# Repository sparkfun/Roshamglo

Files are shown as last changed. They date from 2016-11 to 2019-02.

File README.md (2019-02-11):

SparkFun Roshamglo
=============================================
Giveaway rock, paper, scissors laser tag badge.
SparkFun Roshamglo (https://cdn.sparkfun.com/assets/parts/1/1/9/8/7/14107-01.jpg)

[*SparkFun Roshamglo (KIT-14130)*](https://www.sparkfun.com/products/14130)

The SparkFun Roshamglo is a badge that can be worn with a lanyard clip that has been designed to play Rock Paper Scissors. The board uses the ATtiny84, and has an IR LED and receiver to communicate between badges. To play, simply point the USB connector at your opponents controller up to 5 feet away and press the 5-way switch to the left for rock, up for paper, and right for scissors. The red/green LED will display a solid red for lose, green for win, or alternate red and green for a tie. The Roshamglo uses the [Micronucleaus](https://github.com/micronucleus/micronucleus) bootloader, which allows for USB programming from the Arduino IDE. 
 
 Repository Contents
-------------------
* **/Artwork** - Artwork for custom images (.svg)
* **/Bootloader** - Files needed to install the Micronucleaus bootloader
* **/Datasheets** - Datasheets for various components used (.pdf)
* **/Firmware** - Code used to play Rock Paper Scissors (.ino)
* **/Hardware** - All Eagle design files (.brd, .sch, .dxf, .lbr, .scr)

Documentation
--------------
* **[Hookup Guide](https://learn.sparkfun.com/tutorials/roshamglo-hookup-guide)** - Basic hookup guide.
* **[Roshamglo Project: TV-B-Gone](https://learn.sparkfun.com/tutorials/roshamglo-project-tv-b-gone)**
* **[Hack Your Roshamglo Badge](https://learn.sparkfun.com/tutorials/hack-your-roshamglo-badge)** 

License Information
-------------------
The hardware is released under [Creative Commons ShareAlike 4.0 International](https://creativecommons.org/licenses/by-sa/4.0/).
The code is beerware; if you see me (or any other SparkFun employee) at the local, and you've found our code helpful, please buy us a round!

Distributed as-is; no warranty is given.

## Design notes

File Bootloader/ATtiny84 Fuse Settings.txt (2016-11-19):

avrdude.exe -c arduino -p t84 -P <COM PORT> -b 19200 -U lfuse:w:0xe2:m -U hfuse:w:0xdd:m -U efuse:w:0xfe:m

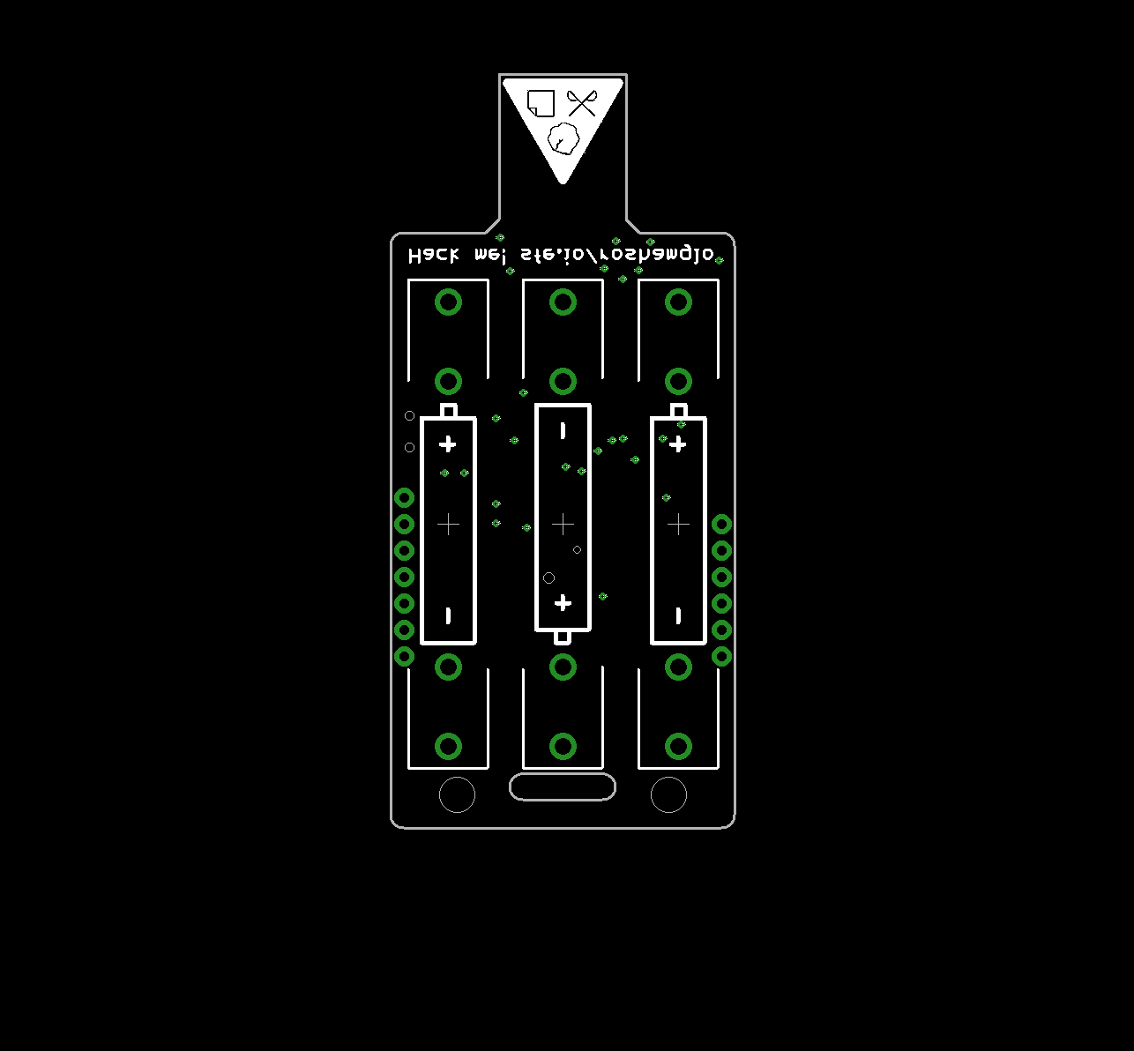
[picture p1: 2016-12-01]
Artwork/Mock-up/roshamglo_bot.png

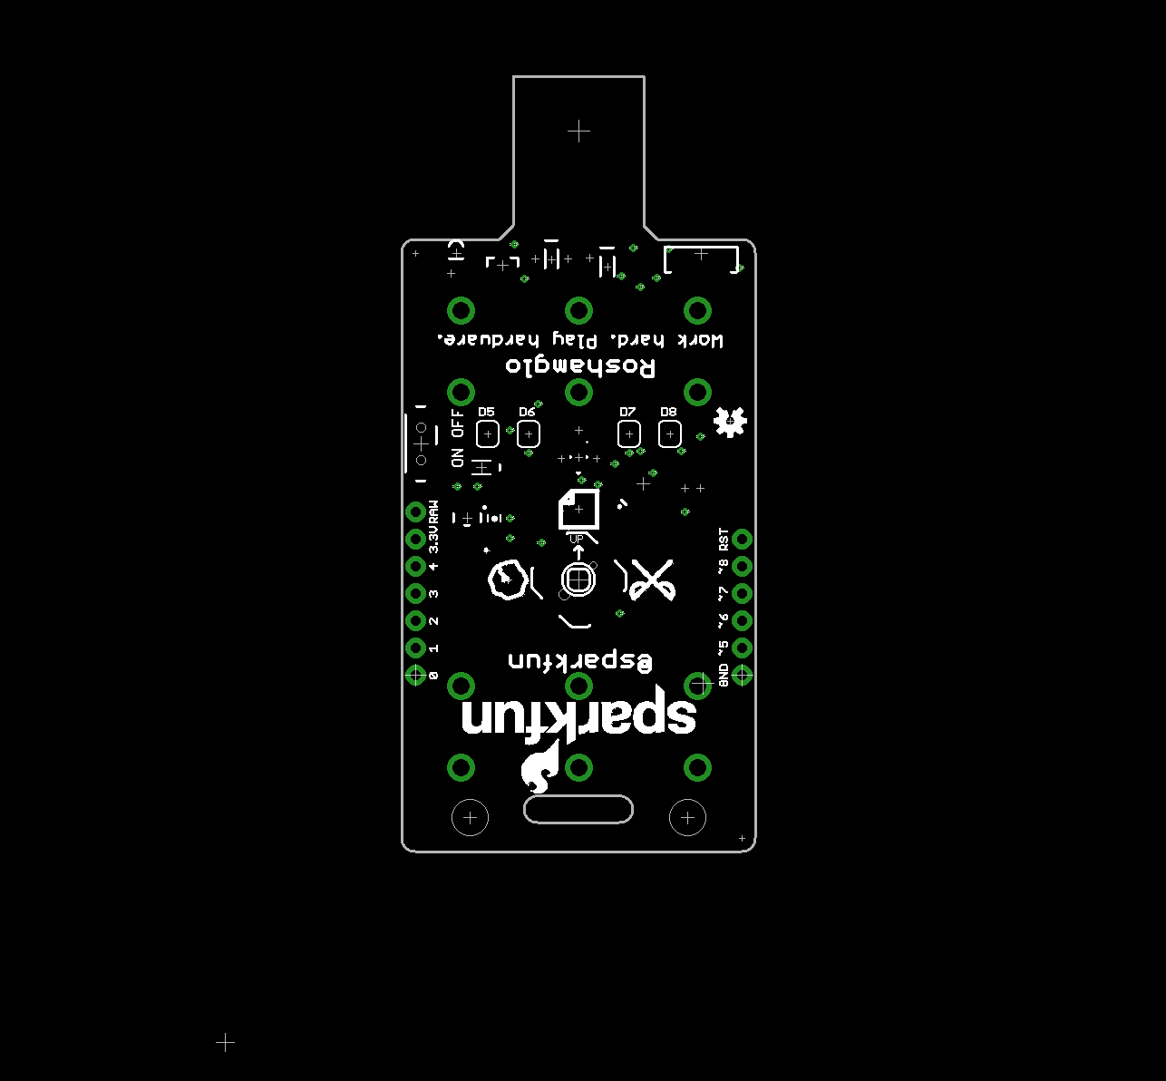
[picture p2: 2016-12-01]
Artwork/Mock-up/roshamglo_top.png

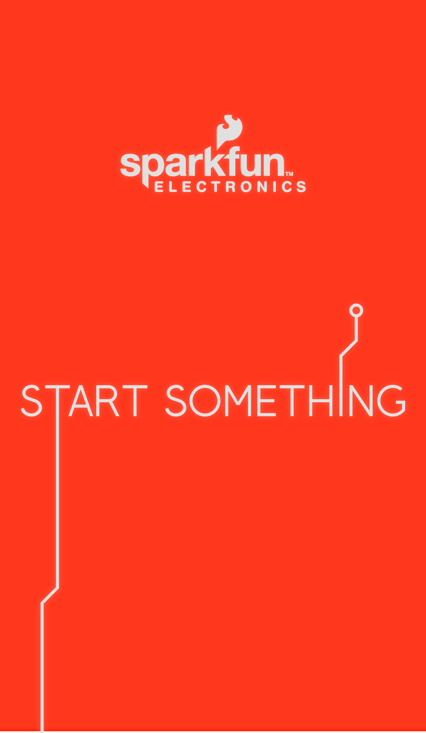
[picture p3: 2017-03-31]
Software/Scoreboard/Scoreboard/startsomething.png

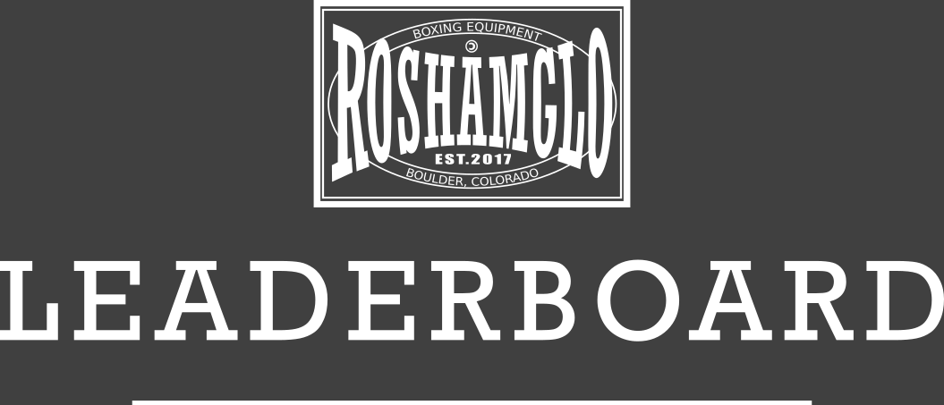
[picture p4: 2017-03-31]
Software/Scoreboard/Scoreboard/roshamglo.png

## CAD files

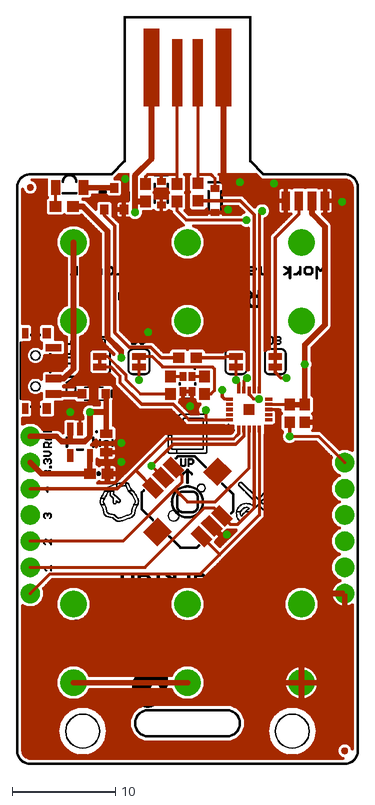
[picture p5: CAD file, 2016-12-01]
Hardware/SparkFun_Roshamglo.dxf
33.2 x 72.6

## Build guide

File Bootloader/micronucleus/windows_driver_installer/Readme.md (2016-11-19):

# Windows driver installation with Zadig #

Zadig is an automated windows driver installer for libusb devices. It will automatically create a driver signature, which prevents issues with unsigned drivers on Windows 10 and earlier. The latest version of Zadig can be found here: [http://zadig.akeo.ie/](http://zadig.akeo.ie/). For convenience, a copy is provided in this folder.

Please proceed as follows to install the Micronucleus driver:

1. Run Zadig_2.1.2.exe. The interface, as shown below, appears.
2. In the menu, go to *Device->Load Preset Device*.  Select micronucleus.cfg.
3. Click the "Install Driver" button.

The driver is now installed and Micronucleus should be ready to use. 

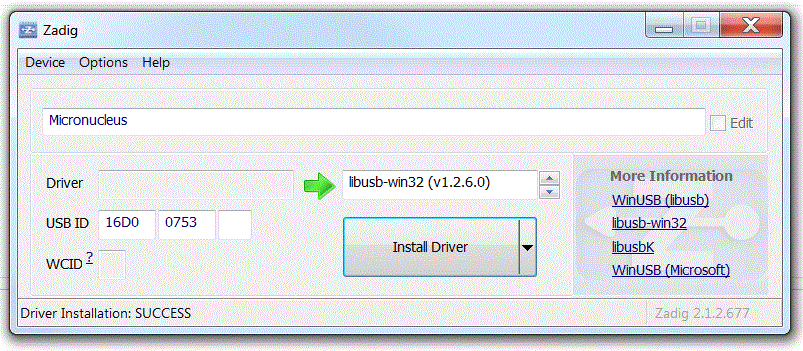
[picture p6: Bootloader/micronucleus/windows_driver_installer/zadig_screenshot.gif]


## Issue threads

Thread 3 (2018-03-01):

Scoreboard Installation Instructions

d1runberg, 2018-03-01:
It would be nice to have a README / setup instructions for the scoreboard side of things in the repo. I will see what I can do to dig in and look at it.  @NPoole do you have any thoughts / willing to do so, it would be ideal, but I know you are on other things ;)

vglisin, 2022-12-24:
Ddi you manage to connect Roshamglo and use it in Arduino IDE? The link provided from https://learn.sparkfun.com/tutorials/hack-your-roshamglo-badge:

https://raw.githubusercontent.com/sparkfun/Arduino_Boards/tiny/IDE_Board_Manager/package_sparkfun_index.json

doesn't exist... 404

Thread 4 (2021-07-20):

Arduino IDE and Roshamglo setup

vglisin, 2021-07-20:
Hello all,
I just tried to hook-up my Roshamglo (got it from friend) and followed the instructions from sparkfun but Arduino IDE definition for Roshamglo are not working. Link mentioned in text is 404:

https://raw.githubusercontent.com/sparkfun/Arduino_Boards/tiny/IDE_Board_Manager/package_sparkfun_index.json

Can you please update documents or make this link working?

Best regards,

vglisin, 2022-12-24:
Stilll doesn't work (404):

https://raw.githubusercontent.com/sparkfun/Arduino_Boards/tiny/IDE_Board_Manager/package_sparkfun_index.json

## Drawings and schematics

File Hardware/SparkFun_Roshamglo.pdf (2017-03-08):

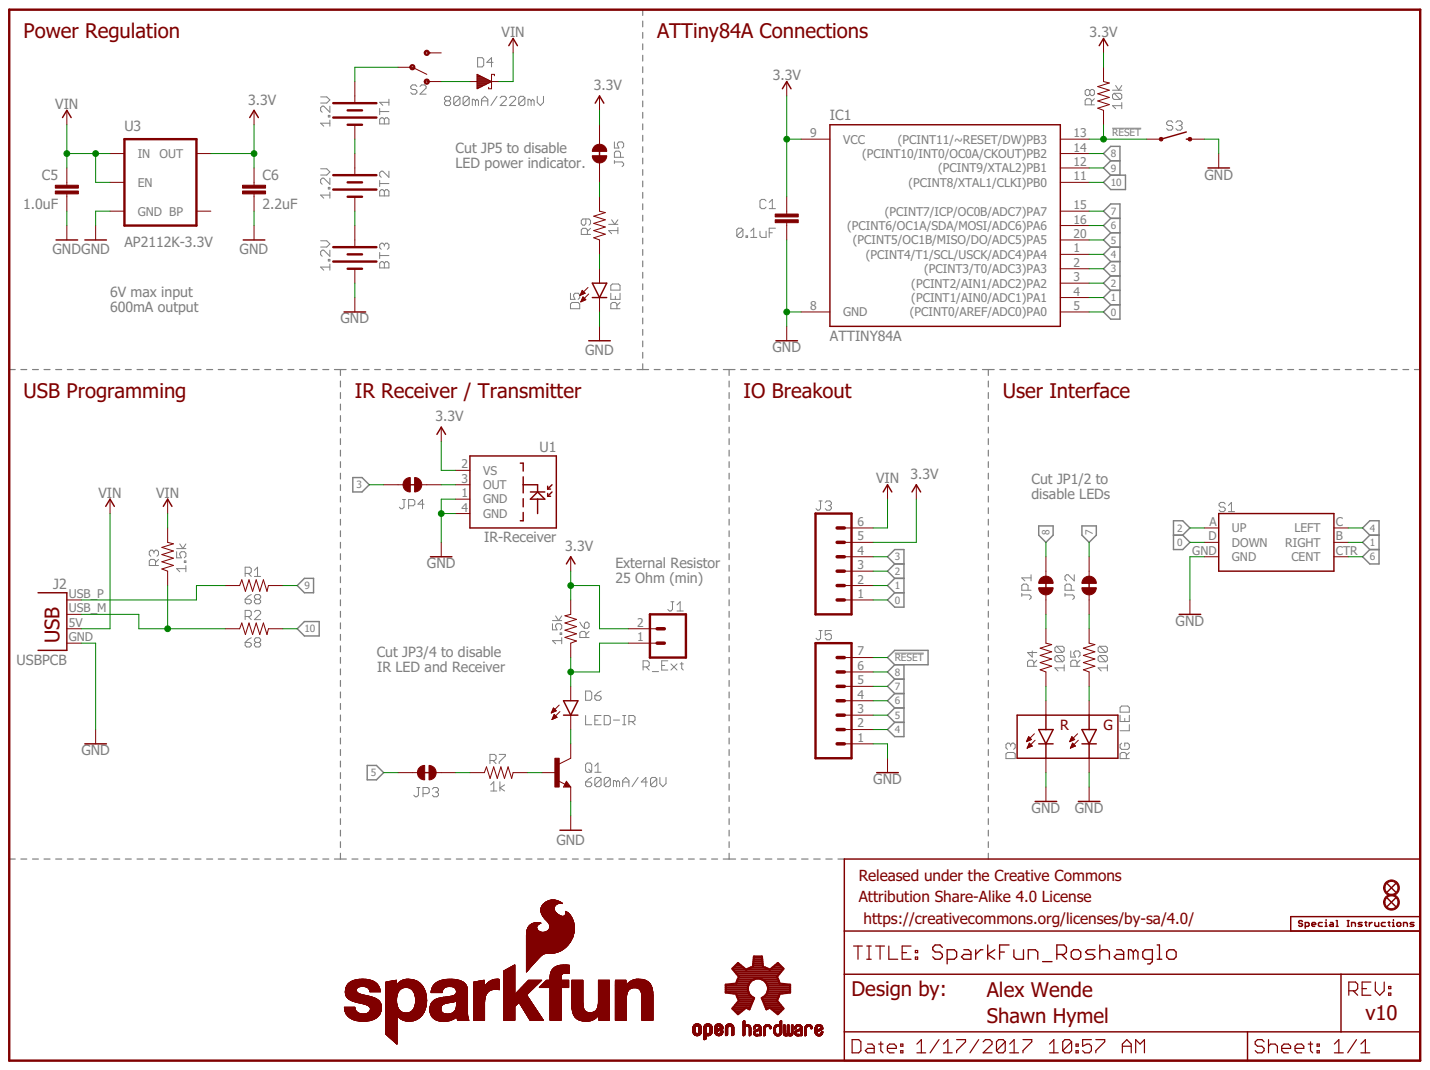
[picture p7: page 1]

Cut JP1/2 to disable LEDs

External Resistor 25 Ohm (min)

Cut JP3/4 to disable
IR LED and Receiver

Released under the Creative Commons Attribution Share-Alike 4.0 License https://creativecommons.org/licenses/by-sa/4.0/

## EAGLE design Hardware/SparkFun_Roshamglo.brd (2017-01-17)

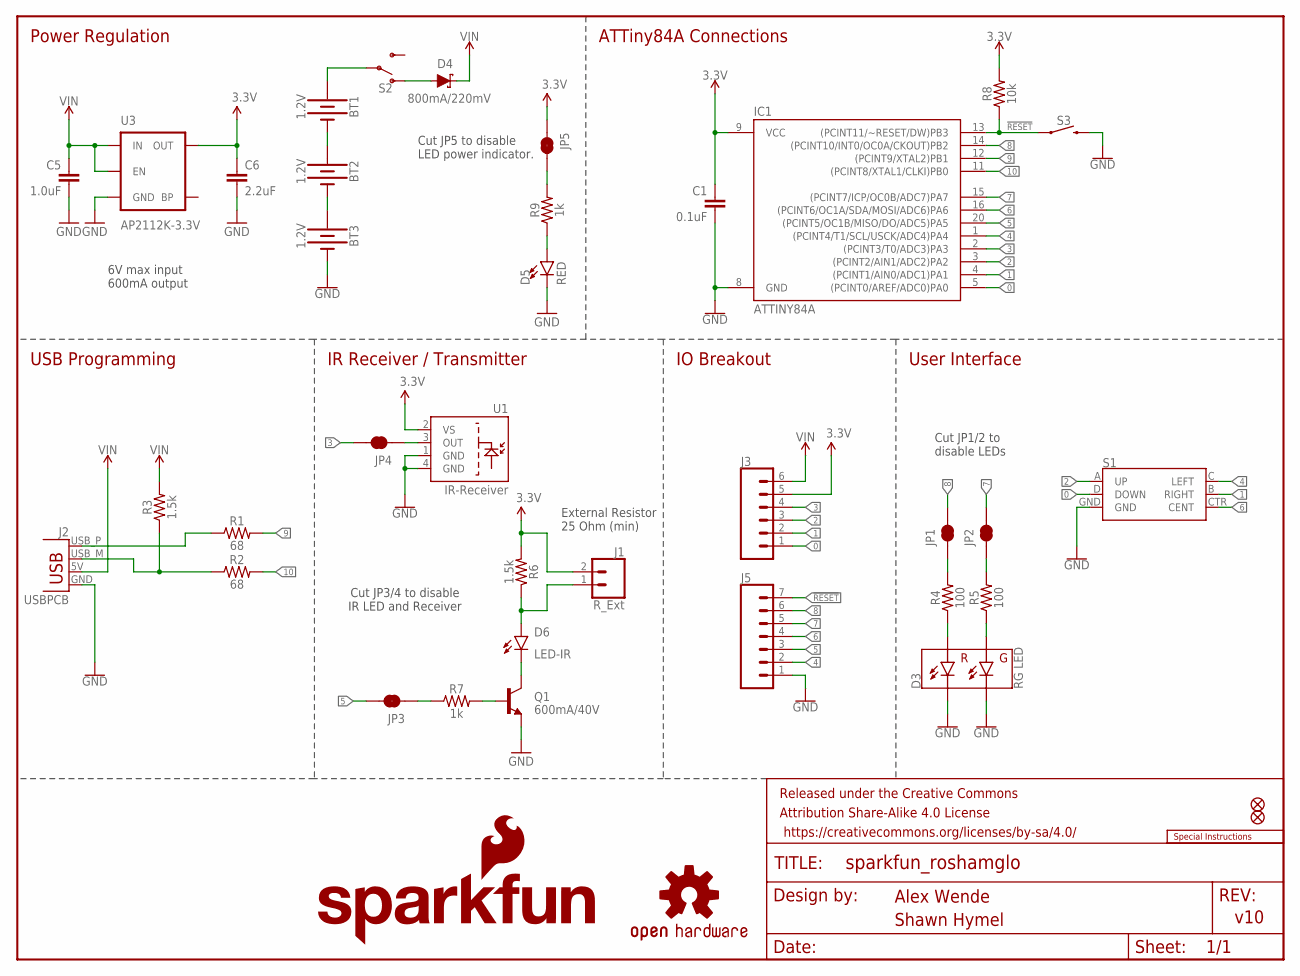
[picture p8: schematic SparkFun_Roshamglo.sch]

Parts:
BT1, BT2, BT3: 1.2V; BATTERY-AAA-KIT
C1: 0.1uF; 0603
C5: 1.0uF; 0805-CAP
C6: 2.2uF; 0603-CAP
D3: RG LED; LTST-C195KGJRKT
D4: 800mA/220mV; SOD-323
D5: RED; LED-0603
D6: LED-IR; SFH4045N
FD1, FD2: FIDUCIALUFIDUCIAL; FIDUCIAL-MICRO
FRAME1: FRAME-LETTER; CREATIVE_COMMONS
IC1: ATTINY84A; QFN20
J1: R_Ext; 1X02_NO_SILK
J2: USBPCB; USB-A-PCB-NOPASTE
J3: CONN_06NO_SILK_FEMALE_PTH; 1X06_NO_SILK
J5: CONN_07NO_SILK; 1X07_NO_SILK
JP1, JP2, JP3, JP4, JP5: JUMPER-SMT_2_NC_TRACE_SILK; SMT-JUMPER_2_NC_TRACE_SILK
LOGO1: OSHW-LOGOS; OSHW-LOGO-S
LOGO2: SFE_LOGO_NAME_FLAME.2_INCH; SFE_LOGO_NAME_FLAME_.2
Q1: 600mA/40V; SOT23-3
R1, R2: 68; 0603
R3, R6: 1.5k; 0603
R4, R5: 100; 0603
R7, R9: 1k; 0603
R8: 10k; 0603
S1: JOYSTICK_MINI
S2: SWITCH-SPDT-SMD-RIGHT-ANGLE; SWITCH_SPST_SMD_A
S3: MOMENTARY-SWITCH-SPST-SMD-4.6X2.8MM; TACTILE_SWITCH_SMD_4.6X2.8MM
U1: IR-Receiver; TSOP75XXXWTR
U3: AP2112K-3.3V; SOT23-5
U$5: SPECIAL_INSTRUCTIONS-ORDERING; ORDERING_INSTRUCTIONS

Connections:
0: IC1.5 ((PCINT0/AREF/ADC0)PA0), J3.1, S1.D (DOWN)
1: IC1.4 ((PCINT1/AIN0/ADC1)PA1), J3.2, S1.B (RIGHT)
2: IC1.3 ((PCINT2/AIN1/ADC2)PA2), J3.3, S1.A (UP)
3: IC1.2 ((PCINT3/T0/ADC3)PA3), J3.4, JP4.2
3.3V: C1.1, C6.1, IC1.9 (VCC), J1.2, J3.5, JP5.1, R6.2, R8.2, U1.2 (VS), U3.5 (OUT)
4: IC1.1 ((PCINT4/T1/SCL/USCK/ADC4)PA4), J5.2, S1.C (LEFT)
5: IC1.20 ((PCINT5/OC1B/MISO/DO/ADC5)PA5), J5.3, JP3.2
6: IC1.16 ((PCINT6/OC1A/SDA/MOSI/ADC6)PA6), J5.4, S1.CTR (CENT)
7: IC1.15 ((PCINT7/ICP/OC0B/ADC7)PA7), J5.5, JP2.2
8: IC1.14 ((PCINT10/INT0/OC0A/CKOUT)PB2), J5.6, JP1.2
9: IC1.12 ((PCINT9/XTAL2)PB1), R1.2
10: IC1.11 ((PCINT8/XTAL1/CLKI)PB0), R2.2
!RESET: IC1.13 ((PCINT11/~RESET/DW)PB3), J5.7, R8.1, S3.1, S3.2 (1)
D+: J2.USB_P (D+), R1.1
D-: J2.USB_M (D-), R2.1, R3.1
GND: BT3.GND@1 (-), C1.2, C5.2, C6.2, D3.P$3 (GC), D3.P$4 (RC), D5.C, IC1.8 (GND), J2.GND, J5.1, Q1.2 (E), S1.GND, S3.3 (2), S3.4 (2), U1.1 (GND), U1.4 (GND), U3.2 (GND)
unnamed: D5.A, R9.1
unnamed: D3.P$2 (RA), R4.1
unnamed: D4.A, S2.1 (O)
unnamed: D3.P$1 (GA), R5.1
unnamed: D6.1 (C), Q1.3 (C)
unnamed: Q1.1 (B), R7.2
unnamed: JP1.1, R4.2
unnamed: JP2.1, R5.2
unnamed: JP4.1, U1.3 (OUT)
unnamed: JP3.1, R7.1
unnamed: JP5.2, R9.2
unnamed: BT1.GND@1 (-), BT2.PWR@1 (+)
unnamed: BT2.GND@1 (-), BT3.PWR@1 (+)
unnamed: D6.2 (A), J1.1, R6.1
VIN: C5.1, D4.C, J2.5V (VBUS), J3.6, R3.2, U3.1 (IN), U3.3 (EN)
V_BATT: BT1.PWR@1 (+), S2.2

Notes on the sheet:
6V max input 600mA output
Power Regulation
USB Programming
ATTiny84A Connections
IR Receiver / Transmitter
User Interface
Alex Wende
Shawn Hymel
v10
IO Breakout
Cut JP1/2 to disable LEDs
Cut JP3/4 to disable IR LED and Receiver
External Resistor 25 Ohm (min)
Cut JP5 to disable LED power indicator.

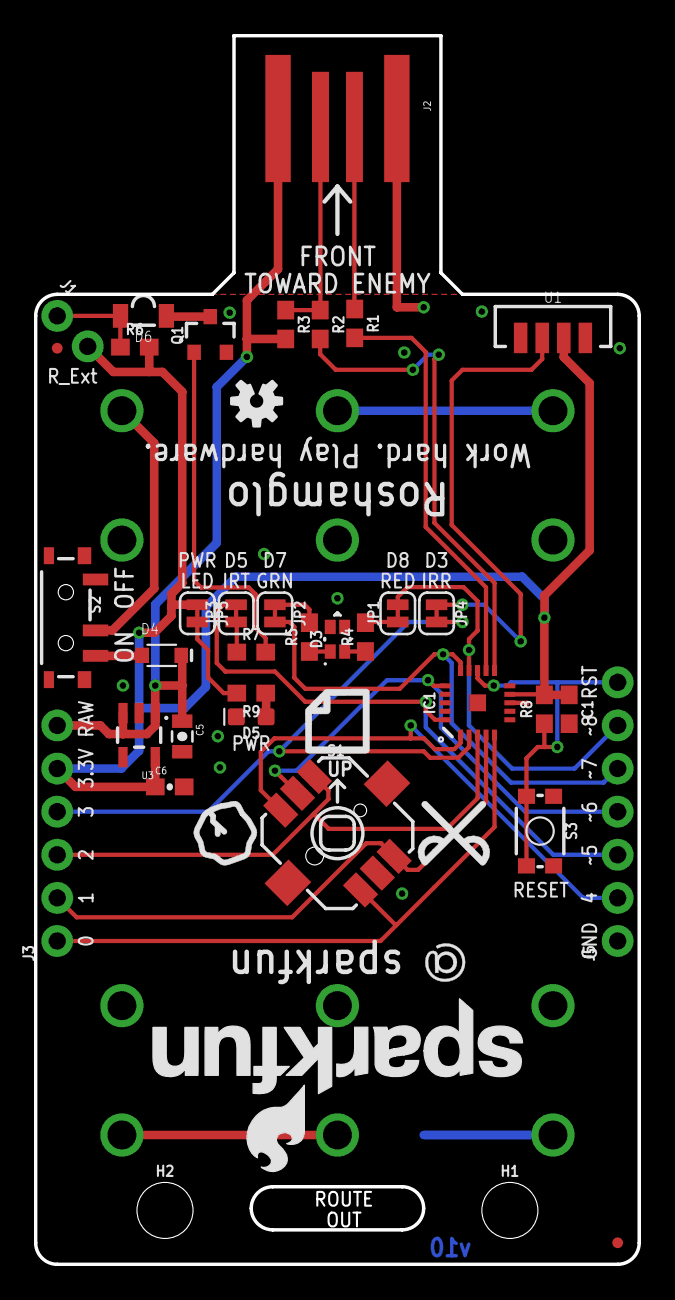
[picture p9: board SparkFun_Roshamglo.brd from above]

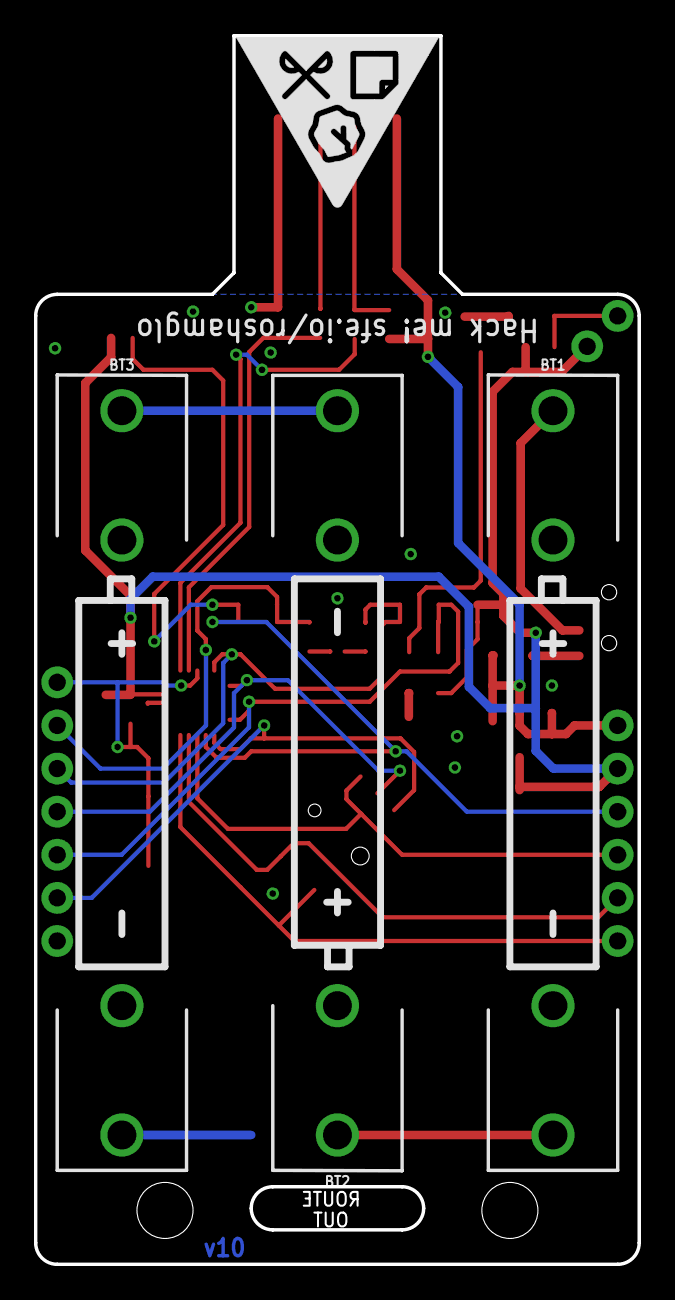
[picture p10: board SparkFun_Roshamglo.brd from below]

Board: 2 copper layers, 35.6 x 72.4 mm, 47 parts (4 on the bottom side), 32 nets.

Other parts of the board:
H1, H2: STAND-OFF
U$1: ROSHAMGLO_PAPER
U$2: ROSHAMGLO_ROCK
U$3: ROSHAMGLO_SCISSORS
U$4: ROSHAMGLO_LOGO_0.4

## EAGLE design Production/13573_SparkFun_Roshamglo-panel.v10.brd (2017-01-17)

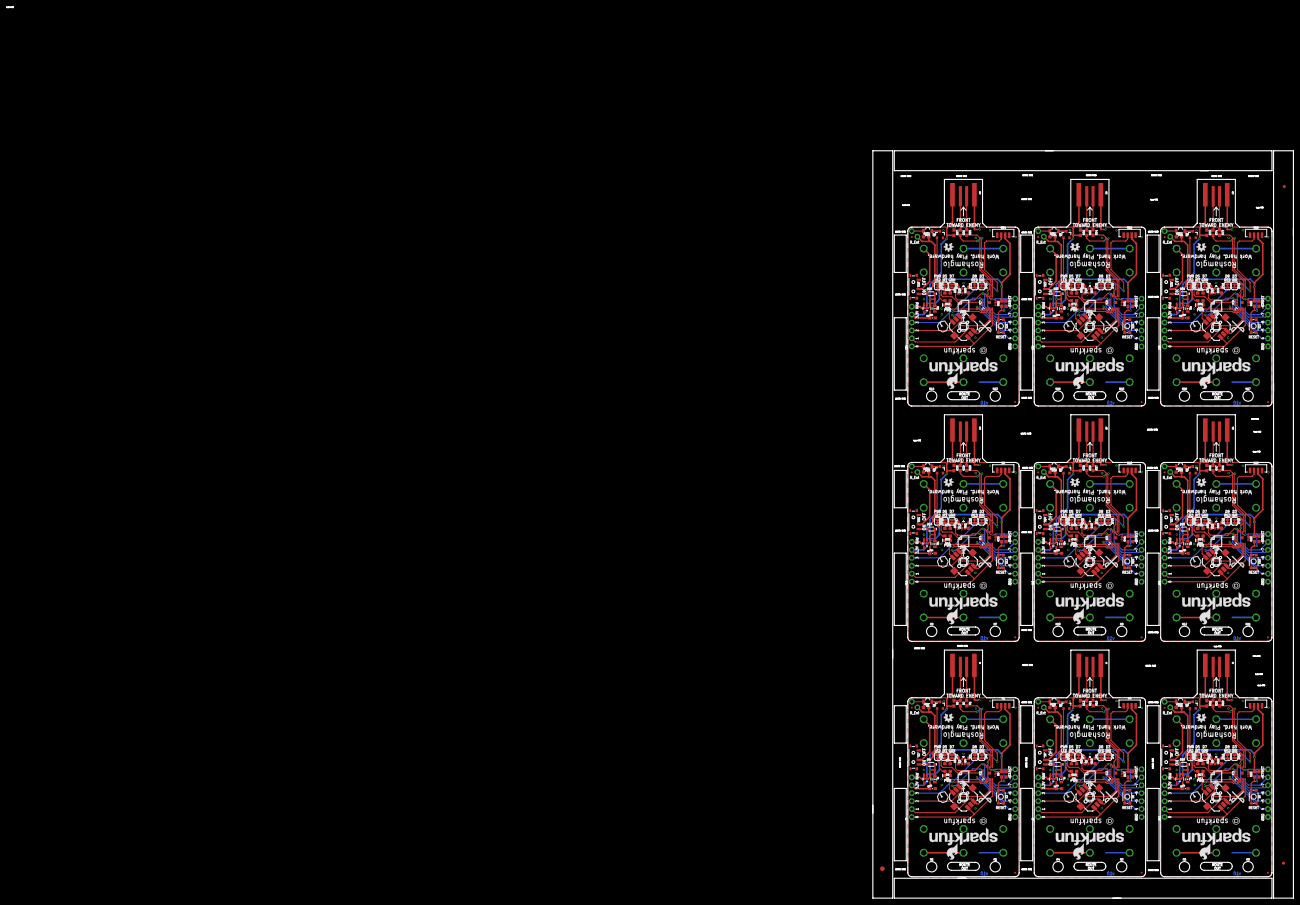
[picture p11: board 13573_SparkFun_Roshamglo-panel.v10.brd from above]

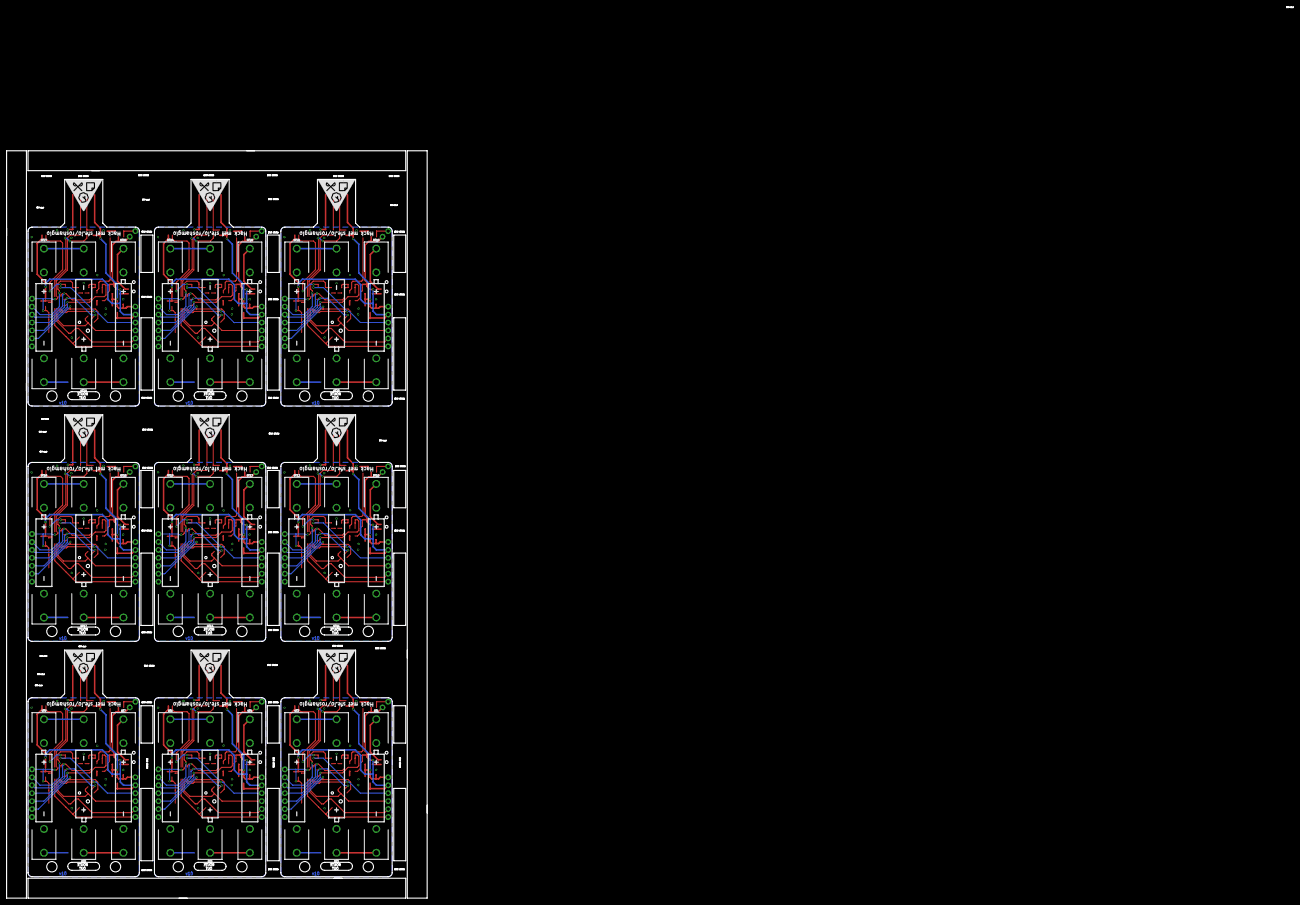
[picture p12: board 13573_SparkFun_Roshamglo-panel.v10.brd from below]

Board: 2 copper layers, 134.4 x 238.8 mm, 408 parts (36 on the bottom side), 288 nets.

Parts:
BT1, BT2, BT3, BT4, BT5, BT6, BT7, BT8, BT9, BT10, BT11, BT12, BT13, BT14, BT15, BT16, BT17, BT18, BT19, BT20, BT21, BT22, BT23, BT24, BT25, BT26, BT27: 1.2V; BATTERY-AAA-KIT
C1, C2, C7, C10, C13, C16, C19, C22, C25: 0.1uF; 0603
C3, C5, C8, C11, C14, C17, C20, C23, C26: 1.0uF; 0805-CAP
C4, C6, C9, C12, C15, C18, C21, C24, C27: 2.2uF; 0603-CAP
D1, D3, D9, D13, D17, D21, D25, D29, D33: RG LED; LTST-C195KGJRKT
D2, D4, D10, D14, D18, D22, D26, D30, D34: 800mA/220mV; SOD-323
D5, D8, D12, D16, D20, D24, D28, D32, D36: RED; LED-0603
D6, D7, D11, D15, D19, D23, D27, D31, D35: LED-IR; SFH4045N
E$1: FIDUCIAL-1.5X3
E$5, E$6: FIDUCIAL-1X2
FD1, FD2, FD3, FD4, FD5, FD6, FD7, FD8, FD9, FD10, FD11, FD12, FD13, FD14, FD15, FD16, FD17, FD18: FIDUCIALUFIDUCIAL; FIDUCIAL-MICRO
H1, H2, H3, H4, H5, H6, H7, H8, H9, H10, H11, H12, H13, H14, H15, H16, H17, H18: STAND-OFF
IC1, IC2, IC3, IC4, IC5, IC6, IC7, IC8, IC9: ATTINY84A; QFN20
J1, J7, J11, J15, J19, J23, J27, J31, J35: R_Ext; 1X02_NO_SILK
J2, J4, J9, J13, J17, J21, J25, J29, J33: USBPCB; USB-A-PCB-NOPASTE
J3, J8, J12, J16, J20, J24, J28, J32, J36: 1X06_NO_SILK
J5, J6, J10, J14, J18, J22, J26, J30, J34: 1X07_NO_SILK
JP1, JP2, JP3, JP4, JP5, JP6, JP7, JP8, JP9, JP10, JP11, JP12, JP13, JP14, JP15, JP16, JP17, JP18, JP19, JP20, JP21, JP22, JP23, JP24, JP25, JP26, JP27, JP28, JP29, JP30, JP31, JP32, JP33, JP34, JP35, JP36, JP37, JP38, JP39, JP40, JP41, JP42, JP43, JP44, JP45: SMT-JUMPER_2_NC_TRACE_SILK
LOGO1, LOGO3, LOGO5, LOGO7, LOGO9, LOGO11, LOGO13, LOGO15, LOGO17: OSHW-LOGOS; OSHW-LOGO-S
LOGO2, LOGO4, LOGO6, LOGO8, LOGO10, LOGO12, LOGO14, LOGO16, LOGO18: SFE_LOGO_NAME_FLAME.2_INCH; SFE_LOGO_NAME_FLAME_.2
Q1, Q2, Q3, Q4, Q5, Q6, Q7, Q8, Q9: 600mA/40V; SOT23-3
R1, R2, R10, R11, R19, R20, R28, R29, R37, R38, R46, R47, R55, R56, R64, R65, R73, R74: 68; 0603
R3, R6, R12, R15, R21, R24, R30, R33, R39, R42, R48, R51, R57, R60, R66, R69, R75, R78: 1.5k; 0603
R4, R5, R13, R14, R22, R23, R31, R32, R40, R41, R49, R50, R58, R59, R67, R68, R76, R77: 100; 0603
R7, R9, R16, R18, R25, R27, R34, R36, R43, R45, R52, R54, R61, R63, R70, R72, R79, R81: 1k; 0603
R8, R17, R26, R35, R44, R53, R62, R71, R80: 10k; 0603
S1, S4, S7, S10, S13, S16, S19, S22, S25: JOYSTICK_MINI
S2, S5, S8, S11, S14, S17, S20, S23, S26: SWITCH_SPST_SMD_A
S3, S6, S9, S12, S15, S18, S21, S24, S27: TACTILE_SWITCH_SMD_4.6X2.8MM
U1, U4, U6, U8, U10, U12, U14, U16, U18: IR-Receiver; TSOP75XXXWTR
U2, U3, U5, U7, U9, U11, U13, U15, U17: AP2112K-3.3V; SOT23-5
U$1, U$5, U$9, U$13, U$17, U$21, U$25, U$29, U$33: ROSHAMGLO_PAPER
U$2, U$6, U$10, U$14, U$18, U$22, U$26, U$30, U$34: ROSHAMGLO_ROCK
U$3, U$7, U$11, U$15, U$19, U$23, U$27, U$31, U$35: ROSHAMGLO_SCISSORS
U$4, U$8, U$12, U$16, U$20, U$24, U$28, U$32, U$36: ROSHAMGLO_LOGO_0.4

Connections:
0: IC1.5, J3.1, S1.D
1: IC1.4, J3.2, S1.B
2: IC1.3, J3.3, S1.A
3: IC1.2, J3.4, JP4.2
3.3V: C1.1, C6.1, IC1.9, J1.2, J3.5, JP5.1, R6.2, R8.2, U1.2, U3.5
3.3V1: C2.1, C4.1, IC2.9, J7.2, J8.5, JP10.1, R15.2, R17.2, U2.5, U4.2
3.3V2: C7.1, C9.1, IC3.9, J11.2, J12.5, JP15.1, R24.2, R26.2, U5.5, U6.2
3.3V3: C10.1, C12.1, IC4.9, J15.2, J16.5, JP20.1, R33.2, R35.2, U7.5, U8.2
3.3V4: C13.1, C15.1, IC5.9, J19.2, J20.5, JP25.1, R42.2, R44.2, U9.5, U10.2
3.3V5: C16.1, C18.1, IC6.9, J23.2, J24.5, JP30.1, R51.2, R53.2, U11.5, U12.2
3.3V6: C19.1, C21.1, IC7.9, J27.2, J28.5, JP35.1, R60.2, R62.2, U13.5, U14.2
3.3V7: C22.1, C24.1, IC8.9, J31.2, J32.5, JP40.1, R69.2, R71.2, U15.5, U16.2
3.3V8: C25.1, C27.1, IC9.9, J35.2, J36.5, JP45.1, R78.2, R80.2, U17.5, U18.2
4: IC1.1, J5.2, S1.C
5: IC1.20, J5.3, JP3.2
6: IC1.16, J5.4, S1.CTR
7: IC1.15, J5.5, JP2.2
8: IC1.14, J5.6, JP1.2
9: IC1.12, R1.2
10: IC1.11, R2.2
11: IC2.14, J6.6, JP6.2
12: IC2.12, R10.2
13: IC2.11, R11.2
14: IC2.15, J6.5, JP7.2
15: IC2.16, J6.4, S4.CTR
16: IC2.20, J6.3, JP8.2
17: IC2.1, J6.2, S4.C
18: IC2.2, J8.4, JP9.2
19: IC2.3, J8.3, S4.A
20: IC2.4, J8.2, S4.B
21: IC2.5, J8.1, S4.D
22: IC3.14, J10.6, JP11.2
23: IC3.12, R19.2
24: IC3.11, R20.2
25: IC3.15, J10.5, JP12.2
26: IC3.16, J10.4, S7.CTR
27: IC3.20, J10.3, JP13.2
28: IC3.1, J10.2, S7.C
29: IC3.2, J12.4, JP14.2
30: IC3.3, J12.3, S7.A
31: IC3.4, J12.2, S7.B
32: IC3.5, J12.1, S7.D
33: IC4.14, J14.6, JP16.2
34: IC4.12, R28.2
35: IC4.11, R29.2
36: IC4.15, J14.5, JP17.2
37: IC4.16, J14.4, S10.CTR
38: IC4.20, J14.3, JP18.2
39: IC4.1, J14.2, S10.C
40: IC4.2, J16.4, JP19.2
41: IC4.3, J16.3, S10.A
42: IC4.4, J16.2, S10.B
43: IC4.5, J16.1, S10.D
44: IC5.14, J18.6, JP21.2
45: IC5.12, R37.2
46: IC5.11, R38.2
47: IC5.15, J18.5, JP22.2
48: IC5.16, J18.4, S13.CTR
49: IC5.20, J18.3, JP23.2
50: IC5.1, J18.2, S13.C
51: IC5.2, J20.4, JP24.2
52: IC5.3, J20.3, S13.A
53: IC5.4, J20.2, S13.B
54: IC5.5, J20.1, S13.D
55: IC6.14, J22.6, JP26.2
56: IC6.12, R46.2
57: IC6.11, R47.2
58: IC6.15, J22.5, JP27.2
59: IC6.16, J22.4, S16.CTR
60: IC6.20, J22.3, JP28.2
61: IC6.1, J22.2, S16.C
62: IC6.2, J24.4, JP29.2
63: IC6.3, J24.3, S16.A
64: IC6.4, J24.2, S16.B
65: IC6.5, J24.1, S16.D
66: IC7.14, J26.6, JP31.2
67: IC7.12, R55.2
68: IC7.11, R56.2
69: IC7.15, J26.5, JP32.2
70: IC7.16, J26.4, S19.CTR
71: IC7.20, J26.3, JP33.2
72: IC7.1, J26.2, S19.C
73: IC7.2, J28.4, JP34.2
74: IC7.3, J28.3, S19.A
75: IC7.4, J28.2, S19.B
76: IC7.5, J28.1, S19.D
77: IC8.14, J30.6, JP36.2
78: IC8.12, R64.2
79: IC8.11, R65.2
80: IC8.15, J30.5, JP37.2
81: IC8.16, J30.4, S22.CTR
82: IC8.20, J30.3, JP38.2
83: IC8.1, J30.2, S22.C
84: IC8.2, J32.4, JP39.2
85: IC8.3, J32.3, S22.A
86: IC8.4, J32.2, S22.B
87: IC8.5, J32.1, S22.D
88: IC9.14, J34.6, JP41.2
89: IC9.12, R73.2
90: IC9.11, R74.2
91: IC9.15, J34.5, JP42.2
92: IC9.16, J34.4, S25.CTR
93: IC9.20, J34.3, JP43.2
94: IC9.1, J34.2, S25.C
95: IC9.2, J36.4, JP44.2
96: IC9.3, J36.3, S25.A
97: IC9.4, J36.2, S25.B
98: IC9.5, J36.1, S25.D
!RESET: IC1.13, J5.7, R8.1, S3.1, S3.2
!RESET1: IC2.13, J6.7, R17.1, S6.1, S6.2
!RESET2: IC3.13, J10.7, R26.1, S9.1, S9.2
!RESET3: IC4.13, J14.7, R35.1, S12.1, S12.2
!RESET4: IC5.13, J18.7, R44.1, S15.1, S15.2
!RESET5: IC6.13, J22.7, R53.1, S18.1, S18.2
!RESET6: IC7.13, J26.7, R62.1, S21.1, S21.2
!RESET7: IC8.13, J30.7, R71.1, S24.1, S24.2
!RESET8: IC9.13, J34.7, R80.1, S27.1, S27.2
D+: J2.USB_P, R1.1
D+1: J4.USB_P, R10.1
D+2: J9.USB_P, R19.1
D+3: J13.USB_P, R28.1
D+4: J17.USB_P, R37.1
D+5: J21.USB_P, R46.1
D+6: J25.USB_P, R55.1
D+7: J29.USB_P, R64.1
D+8: J33.USB_P, R73.1
D-: J2.USB_M, R2.1, R3.1
D-1: J4.USB_M, R11.1, R12.1
D-2: J9.USB_M, R20.1, R21.1
D-3: J13.USB_M, R29.1, R30.1
D-4: J17.USB_M, R38.1, R39.1
D-5: J21.USB_M, R47.1, R48.1
D-6: J25.USB_M, R56.1, R57.1
D-7: J29.USB_M, R65.1, R66.1
D-8: J33.USB_M, R74.1, R75.1
GND: BT3.GND@1, C1.2, C5.2, C6.2, D3.P$3, D3.P$4, D5.C, IC1.8, J2.GND, J5.1, Q1.2, S1.GND, S3.3, S3.4, U1.1, U1.4, U3.2
GND1: BT6.GND@1, C2.2, C3.2, C4.2, D1.P$3, D1.P$4, D8.C, IC2.8, J4.GND, J6.1, Q2.2, S4.GND, S6.3, S6.4, U2.2, U4.1, U4.4
GND2: BT9.GND@1, C7.2, C8.2, C9.2, D9.P$3, D9.P$4, D12.C, IC3.8, J9.GND, J10.1, Q3.2, S7.GND, S9.3, S9.4, U5.2, U6.1, U6.4
GND3: BT12.GND@1, C10.2, C11.2, C12.2, D13.P$3, D13.P$4, D16.C, IC4.8, J13.GND, J14.1, Q4.2, S10.GND, S12.3, S12.4, U7.2, U8.1, U8.4
GND4: BT15.GND@1, C13.2, C14.2, C15.2, D17.P$3, D17.P$4, D20.C, IC5.8, J17.GND, J18.1, Q5.2, S13.GND, S15.3, S15.4, U9.2, U10.1, U10.4
GND5: BT18.GND@1, C16.2, C17.2, C18.2, D21.P$3, D21.P$4, D24.C, IC6.8, J21.GND, J22.1, Q6.2, S16.GND, S18.3, S18.4, U11.2, U12.1, U12.4
GND6: BT21.GND@1, C19.2, C20.2, C21.2, D25.P$3, D25.P$4, D28.C, IC7.8, J25.GND, J26.1, Q7.2, S19.GND, S21.3, S21.4, U13.2, U14.1, U14.4
GND7: BT24.GND@1, C22.2, C23.2, C24.2, D29.P$3, D29.P$4, D32.C, IC8.8, J29.GND, J30.1, Q8.2, S22.GND, S24.3, S24.4, U15.2, U16.1, U16.4
GND8: BT27.GND@1, C25.2, C26.2, C27.2, D33.P$3, D33.P$4, D36.C, IC9.8, J33.GND, J34.1, Q9.2, S25.GND, S27.3, S27.4, U17.2, U18.1, U18.4
unnamed: D5.A, R9.1
unnamed: D3.P$2, R4.1
unnamed: D4.A, S2.1
unnamed: D3.P$1, R5.1
unnamed: D6.1, Q1.3
unnamed: Q1.1, R7.2
unnamed: JP1.1, R4.2
unnamed: JP2.1, R5.2
unnamed: JP4.1, U1.3
unnamed: JP3.1, R7.1
unnamed: JP5.2, R9.2
unnamed: BT1.GND@1, BT2.PWR@1
unnamed: BT2.GND@1, BT3.PWR@1
unnamed: D6.2, J1.1, R6.1
unnamed: D1.P$2, R13.1
unnamed: D1.P$1, R14.1
unnamed: BT4.GND@1, BT5.PWR@1
unnamed: BT5.GND@1, BT6.PWR@1
unnamed: D2.A, S5.1
unnamed: JP6.1, R13.2
unnamed: JP7.1, R14.2
unnamed: D7.1, Q2.3
unnamed: Q2.1, R16.2
unnamed: JP9.1, U4.3
unnamed: JP8.1, R16.1
unnamed: D7.2, J7.1, R15.1
unnamed: D8.A, R18.1
unnamed: JP10.2, R18.2
unnamed: D9.P$2, R22.1
unnamed: D9.P$1, R23.1
unnamed: BT7.GND@1, BT8.PWR@1
unnamed: BT8.GND@1, BT9.PWR@1
unnamed: D10.A, S8.1
unnamed: JP11.1, R22.2
unnamed: JP12.1, R23.2
unnamed: D11.1, Q3.3
unnamed: Q3.1, R25.2
unnamed: JP14.1, U6.3
unnamed: JP13.1, R25.1
unnamed: D11.2, J11.1, R24.1
unnamed: D12.A, R27.1
unnamed: JP15.2, R27.2
unnamed: D13.P$2, R31.1
unnamed: D13.P$1, R32.1
unnamed: BT10.GND@1, BT11.PWR@1
unnamed: BT11.GND@1, BT12.PWR@1
unnamed: D14.A, S11.1
unnamed: JP16.1, R31.2
unnamed: JP17.1, R32.2
unnamed: D15.1, Q4.3
unnamed: Q4.1, R34.2
unnamed: JP19.1, U8.3
unnamed: JP18.1, R34.1
unnamed: D15.2, J15.1, R33.1
unnamed: D16.A, R36.1
unnamed: JP20.2, R36.2
unnamed: D17.P$2, R40.1
unnamed: D17.P$1, R41.1
unnamed: BT13.GND@1, BT14.PWR@1
unnamed: BT14.GND@1, BT15.PWR@1
unnamed: D18.A, S14.1
unnamed: JP21.1, R40.2
unnamed: JP22.1, R41.2
unnamed: D19.1, Q5.3
unnamed: Q5.1, R43.2
unnamed: JP24.1, U10.3
unnamed: JP23.1, R43.1
unnamed: D19.2, J19.1, R42.1
unnamed: D20.A, R45.1
unnamed: JP25.2, R45.2
unnamed: D21.P$2, R49.1
unnamed: D21.P$1, R50.1
unnamed: BT16.GND@1, BT17.PWR@1
unnamed: BT17.GND@1, BT18.PWR@1
unnamed: D22.A, S17.1
unnamed: JP26.1, R49.2
unnamed: JP27.1, R50.2
unnamed: D23.1, Q6.3
unnamed: Q6.1, R52.2
unnamed: JP29.1, U12.3
unnamed: JP28.1, R52.1
unnamed: D23.2, J23.1, R51.1
unnamed: D24.A, R54.1
unnamed: JP30.2, R54.2
unnamed: D25.P$2, R58.1
unnamed: D25.P$1, R59.1
unnamed: BT19.GND@1, BT20.PWR@1
unnamed: BT20.GND@1, BT21.PWR@1
unnamed: D26.A, S20.1
unnamed: JP31.1, R58.2
unnamed: JP32.1, R59.2
unnamed: D27.1, Q7.3
unnamed: Q7.1, R61.2
unnamed: JP34.1, U14.3
unnamed: JP33.1, R61.1
unnamed: D27.2, J27.1, R60.1
unnamed: D28.A, R63.1
unnamed: JP35.2, R63.2
unnamed: D29.P$2, R67.1
unnamed: D29.P$1, R68.1
unnamed: BT22.GND@1, BT23.PWR@1
unnamed: BT23.GND@1, BT24.PWR@1
unnamed: D30.A, S23.1
unnamed: JP36.1, R67.2
unnamed: JP37.1, R68.2
unnamed: D31.1, Q8.3
unnamed: Q8.1, R70.2
unnamed: JP39.1, U16.3
unnamed: JP38.1, R70.1
unnamed: D31.2, J31.1, R69.1
unnamed: D32.A, R72.1
unnamed: JP40.2, R72.2
unnamed: D33.P$2, R76.1
unnamed: D33.P$1, R77.1
unnamed: BT25.GND@1, BT26.PWR@1
unnamed: BT26.GND@1, BT27.PWR@1
unnamed: D34.A, S26.1
unnamed: JP41.1, R76.2
unnamed: JP42.1, R77.2
unnamed: D35.1, Q9.3
unnamed: Q9.1, R79.2
unnamed: JP44.1, U18.3
unnamed: JP43.1, R79.1
unnamed: D35.2, J35.1, R78.1
unnamed: D36.A, R81.1
unnamed: JP45.2, R81.2
VIN: C5.1, D4.C, J2.5V, J3.6, R3.2, U3.1, U3.3
VIN1: C3.1, D2.C, J4.5V, J8.6, R12.2, U2.1, U2.3
VIN2: C8.1, D10.C, J9.5V, J12.6, R21.2, U5.1, U5.3
VIN3: C11.1, D14.C, J13.5V, J16.6, R30.2, U7.1, U7.3
VIN4: C14.1, D18.C, J17.5V, J20.6, R39.2, U9.1, U9.3
VIN5: C17.1, D22.C, J21.5V, J24.6, R48.2, U11.1, U11.3
VIN6: C20.1, D26.C, J25.5V, J28.6, R57.2, U13.1, U13.3
VIN7: C23.1, D30.C, J29.5V, J32.6, R66.2, U15.1, U15.3
VIN8: C26.1, D34.C, J33.5V, J36.6, R75.2, U17.1, U17.3
V_BATT: BT1.PWR@1, S2.2
V_BATT1: BT4.PWR@1, S5.2
V_BATT2: BT7.PWR@1, S8.2
V_BATT3: BT10.PWR@1, S11.2
V_BATT4: BT13.PWR@1, S14.2
V_BATT5: BT16.PWR@1, S17.2
V_BATT6: BT19.PWR@1, S20.2
V_BATT7: BT22.PWR@1, S23.2
V_BATT8: BT25.PWR@1, S26.2

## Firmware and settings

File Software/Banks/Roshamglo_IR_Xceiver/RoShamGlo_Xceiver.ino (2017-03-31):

#include <IntarIR.h>
IntarIR intar_ir;

#define USER_ID           0x000000
#define IR_RECEIVER_PIN   4
#define IR_LED_PIN        3

// Shot packet message
uint8_t shot_packet[] = {0x00, 0x00, 0x00, 0x00};
uint8_t shot_packet_size = 4;

// Packet buffer
uint8_t packet[MAX_PACKET_SIZE];

int transmit = 0;

void setup() {
  Serial.begin(9600);

  pinMode(IR_LED_PIN,OUTPUT);
  digitalWrite(IR_LED_PIN,LOW);
  
  intar_ir.begin(IR_RECEIVER_PIN);
  intar_ir.enableTransmitter();
  intar_ir.enableReceiver();
}

void loop() {
  uint8_t num_bytes;
  uint32_t playerID, playerID_low, playerID_middle, playerID_high;
  // Read opponent data
  if(intar_ir.available())
  {
    memset(packet, 0, MAX_PACKET_SIZE);
    num_bytes = intar_ir.read(packet);
    
    if(num_bytes!=0 && num_bytes!=RECV_ERROR) // Valid packet
    {      
      playerID_high = packet[0];
      playerID_middle = packet[1];
      playerID_low = packet[2];
      playerID = (playerID_high<<16) + (playerID_middle<<8) + playerID_low;
      
      if(playerID != USER_ID) // Not our data
      {
        transmit = 1;
        shot_packet[3] = 1; // Set acknoledge

        if(packet[4]==1 || packet[4]==2) //Recieved our move
        {
          shot_packet[3] = 2; // Update acknoledge
        }
      }
    }
  }

  // Transmit our data
  if(transmit)
  {
    intar_ir.disableReceiver();
    
    intar_ir.send(shot_packet, shot_packet_size);
    delay(32);
    intar_ir.send(shot_packet, shot_packet_size);
    
    intar_ir.flushTransmitter();
    intar_ir.enableReceiver();
    delay(200);
  }

  if(packet[4]==2 && shot_packet[3] == 2)
  {
    intar_ir.disableReceiver();
    
    Serial.print(playerID,HEX);
    Serial.print(',');
    Serial.println(packet[3],HEX);
    
    packet[0] = 0;
    packet[1] = 0;
    packet[2] = 0;
    packet[3] = 0; 
    packet[4] = 0;
    
    transmit = 0;
    delay(200);
    intar_ir.enableReceiver();
  }
}

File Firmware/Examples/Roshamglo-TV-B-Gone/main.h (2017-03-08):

/*
Roshamglo branch
Date: 07 Mar. 2017
By SparkFun Electronics https://www.sparkfun.com/
Modified to run on ATTiny84-based Roshamglo board

Last Updated: 22 Oct. 2016
By Gabriel Staples, http://www.ElectricRCAircraftGuy.com 
-My contact info is available by clicking the "Contact Me" tab at the top of my website.
*/

#include <avr/pgmspace.h>

// The TV-B-Gone for Arduino can use either the EU (European Union) or the NA (North America) database of POWER CODES
// EU is for Europe, Middle East, Australia, New Zealand, and some countries in Africa and South America
// NA is for North America, Asia, and the rest of the world not covered by EU

// Two regions!
#define NA 1
#define EU 0
#define REGION NA       // Set to NA or EU

// What pins do what
#define LED 7           //LED indicator pin (usually 13)
#define IRLED 5         //the IR sender LED 
#define TRIGGER 6       //the button pin; NB: this pin is "hard-coded" in the sleepNow() function in the primary .ino file by means of using external interrupt 0, which is hard-wired to pin 2

// Lets us calculate the size of the NA/EU databases
#define NUM_ELEM(x) (sizeof (x) / sizeof (*(x)));

// set define to 0 to turn off debug output
#define DEBUG 0
#define DEBUGP(x) if (DEBUG == 1) { x ; }

// Shortcut to insert single, non-optimized-out nop
#define NOP __asm__ __volatile__ ("nop")

// Tweak this if neccessary to change timing
// -for 8MHz Arduinos, a good starting value is 11
// -for 16MHz Arduinos, a good starting value is 25
#define DELAY_CNT 11

// Makes the codes more readable. the OCRA is actually
// programmed in terms of 'periods' not 'freqs' - that
// is, the inverse!
#define freq_to_timerval(x) (F_CPU / 8 / x - 1)

// The structure of compressed code entries
struct IrCode {
  uint8_t timer_val;
  uint8_t numpairs;
  uint8_t bitcompression;
  uint16_t const *times;
  uint8_t const *codes;
};

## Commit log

2016-11-19 Added bootloader and Arduino board definition file
    [micronucleus.cfg]
2016-11-28 Changed to SMD IR led and receiver in datasheets. Added IR receiver to local lib.
2016-11-28 Added IR LED symbol and footprint
2016-11-28 Added IR LED to library
2016-11-29 V01 Hardware
    - Initial Circuit Layout
    - Added Schottky diode to library
    - Added Prod_ID attributes for new parts
    [SparkFun_Roshamglo.brd, SparkFun_Roshamglo.sch]
2016-11-29 Added version number to PCB
    [SparkFun_Roshamglo.brd]
2016-11-29 V01 changes
    - Fixed version number DRC error
    - Added pin 1 marker to Attiny84 to make orientation obvious after
    placement.
    [SparkFun_Roshamglo.brd, SparkFun_Roshamglo.sch]
2016-11-29 v01 changes
    - Extended USB connector length 0.1"
    - Added jumpers to pins 7 and 8
    - Changed project name silk to single word
    - Added PWM pin labels
    - Rotated pin names 90 deg
    [SparkFun_Roshamglo.brd, SparkFun_Roshamglo.sch]
2016-11-30 v01 changes
    - Added labels to jumpers
    - Cleaned up a couple traces
    [SparkFun_Roshamglo.brd, SparkFun_Roshamglo.sch]
2016-11-30 Fixed DRC Errors
    [SparkFun_Roshamglo.brd]
2016-11-30 Design Review Changes
    - removed ISP
    - added 10k to reset pin
    - broke out reset pin
    - Moved components away from SS pins
    - Changed route out to dimmention layer
    - moved lanyard hole away from edge of board
    [SparkFun_Roshamglo.brd, SparkFun_Roshamglo.sch]
2016-12-01 Fixed Battery t-stop and b-stop
    [SparkFun_Roshamglo.brd, SparkFun_Roshamglo.sch]
2016-12-01 Added logos
    [SparkFun_Roshamglo.brd]
2016-12-01 Spun silk text to face the same way
    [SparkFun_Roshamglo.brd]
2016-12-01 Fixed DRC error and added text for LEDs
    [SparkFun_Roshamglo.brd]
2016-12-01 Added mock-up artwork
    [SparkFun_Roshamglo.dxf]
2016-12-01 Moved Roshamglo logo up and added fill silk to go off edge of USB connector
    [SparkFun_Roshamglo.brd]
2016-12-01 Replaced transistor
    [SparkFun_Roshamglo.brd, SparkFun_Roshamglo.sch]
2016-12-05 Fixed QC issues
    - Added RES-00824 to BOM
    - Added standoff measurments
    - Changed "ROUTE OUT" to dimention layer
    [SparkFun_Roshamglo.brd]
2016-12-15 v02 Changes
    - Moved IR LED to GPIO 5
    - Moved red and green LEDs to GPIO 7 and 8
    - Moved IR receiver to GPIO 3
    - Moved center switch to GPIO 6
    - Increased distance between batteries
    - Increased board size to 1.4"
    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
    [SparkFun_Roshamglo.brd, SparkFun_Roshamglo.sch]
2016-12-15 Fixed V02 DRC errors
    [SparkFun_Roshamglo.brd]
2016-12-20 v02 changes
    Added power LED
    Added external parallel resistor
    [SparkFun_Roshamglo.brd, SparkFun_Roshamglo.sch]
2016-12-20 v02 changes
    - Switch back to old size for lanyard clip
    - Changed the "@" to proportional
    - Moved pin 4 to other header to leave more room for battery terminal
    soldering
    [SparkFun_Roshamglo.brd, SparkFun_Roshamglo.sch]
2016-12-20 Minor fixes
    Added ordering instructions to bottom of board
    Removed right angles in traces
    [SparkFun_Roshamglo.brd, SparkFun_Roshamglo.sch]
2016-12-21 Adjusted lanyard clip size
    My change back in v02 wasn't quite what it was. Going back to 0.4" width
    [SparkFun_Roshamglo.brd]
2016-12-21 Updating code
    Game roughly works. The board still needs to be reset after each game
    though.
    [Roshamglo.ino]
2017-01-06 Firmware changes
    - Introduced a random delay to minimize likelihood of transmitting at
    the same time.
    - Added EEPROM to store the board's ID, last opponent's ID, and number
    of times those boards have played each other.
2017-01-11 V10 changes
    - Removed zener diodes
    - Changed 33ohm IR LED resistor to 2.55k
    - Removed paste on USB conn
    [SparkFun_Roshamglo.brd, SparkFun_Roshamglo.sch]
2017-01-12 v10 - replaced 2.55k resistor with 2.2k
    [SparkFun_Roshamglo.brd, SparkFun_Roshamglo.sch]
2017-01-12 V1.0
    - Fixed some bugs
    - Decreased gameplay time
    - Added better random number generator
    [Roshamglo.ino]
2017-01-12 Added @ symbol artwork to pcb
    [SparkFun_Roshamglo.brd]
2017-01-12 Design Review changes
    Replaced some silk, and moved a via
    [SparkFun_Roshamglo.brd, SparkFun_Roshamglo.sch]
2017-01-17 Changed line width to 0.001 for custom artwork to prevent long CAM jobs.
    [SparkFun_Roshamglo.brd]
2017-02-21 v1.3 Changes
    - Added sleep mode to save power during standby
    - Added self test code used in production testing
    - Replaced 2-byte ID with 3-byte ID
    - Added fading LED in standby mode to show the board is on and running
    - timerDelay function now takes the number of milliseconds to delay for
    instead of number * 32ms
    [Roshamglo.ino]
2017-03-08 Added pdf schematic
2017-03-31 Adding Arduino Source for Points Banks

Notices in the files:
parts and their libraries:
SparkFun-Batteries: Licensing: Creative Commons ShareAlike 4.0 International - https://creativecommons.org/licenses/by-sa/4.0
